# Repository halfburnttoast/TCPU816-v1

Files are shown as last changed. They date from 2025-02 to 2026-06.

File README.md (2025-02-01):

# TCPU816 - Version 1

This is the official repository for my TCPU816, 8-bit, homebrew computer. The computer is a completely custom architecture using 74-series logic gates and EEPROMs. 

The overall goals of this project were to:
* Minimize the chip count.
* Use the fewest EEPROM's possible.
* Avoid using PLAs, CPLDs, and microcontrollers. 
* Maximize stability and operating speed.
* Leave the most amount of RAM possible to the user.
* Make the project fully open-source for others to tinker with and learn from.

## To Do (in no particular order)

* Create standalone emulator for this computer (in C/Rust/Python/etc...)
* Improve the assembler to allow for a more 6502-style syntax (rather than relying on opcode names to define the variants).
* Research adding interrupts to the computer and what kinds of changes would need to happen.
* See the TODO.docx for bugs and improvements. This can be found in 'TCPU816 Computer v1/Hardware/TODO.docx'.

## Purpose

I've had a strong interest in computer design since I was a teenager and had developed multiple CPU implementations in software. But, I've always had a dream of making my own computer from scratch on real hardware. 

The project has been a great learning experience and challenge. In several ways, it let me break away from traditional CPU architecture and test out experimental designs (specifically, minimizing buffer registers and repurposing the MAR to increase efficiency).

## Features and shortcomings
I've tried to keep this computer streamlined and minimalist, focusing on balancing a low chip count and efficiency. But, focusing on one design philosophy usually excludes the other. So, after careful design, the computer has taken the following form:

* Rich, complex instruction set comparable to the 65C02 (but not binary compatible).
* Heavy optimization of the sequencing logic to allow the microcode to fit onto just two EEPROMs.
* Internal memory and IO separation. The external IO exists on a separate address space from the internal memory. This preserves the usable RAM space while allowing the IO cards to make use of the full 16-bit address bus. This also helps reduce address decoding logic. 
* Minimal ROM space. In order to maximize the available RAM, the ROM is limited t a 2Kb block at the beginning of the memory address space. The intention is that this 2Kb block will contain a small monitor and/or bootloader. The actual program storage will be from an SD card on the external bus. 
* Multi-phase clock generation. The phases allow for proper timing between events on the board to eliminate race conditions. It also allows for faster operating speeds overall because it allows multiple conflicting microinstructions to happen during the same CPU cycle without threatening the stability.

There are some pitfalls with this design, however:

* Due to the minimalist ALU design, logic operations take a lot longer to run.
* The computer does not support interrupts at all. This may be something that can be addressed later on. But, for now, there is no clean solution for adding interrupt support. For now, IO is done through polling.
* The design of the address controller limits the possible operating frequency to the maximum response time of the RAM and ROM. This is okay for me because I don't expect (or need) this computer to run any faster than around 3.3MHz. But, the design decisions for this computer make the architecture difficult to scale upwards.

## Licensing 

Licensing hardware is notoriously difficult. Ideally, I'd like the software to be under the GPLv2 license and the hardware to be under the CERN-OHL-S-2.0 license. 

I wouldn't be able to do all this without the vast open-source resources available for electrical engineering and computer design, a lot of which is open source. So, this is my contribution back to that. Hopefully this computer can serve as a learning tool. But, even if the design just gives you an idea or a different way to look at computer design, that's good enough for me!

I'd appreciate a reference if you build off of this design and encourage you to share your improvements back with the community.

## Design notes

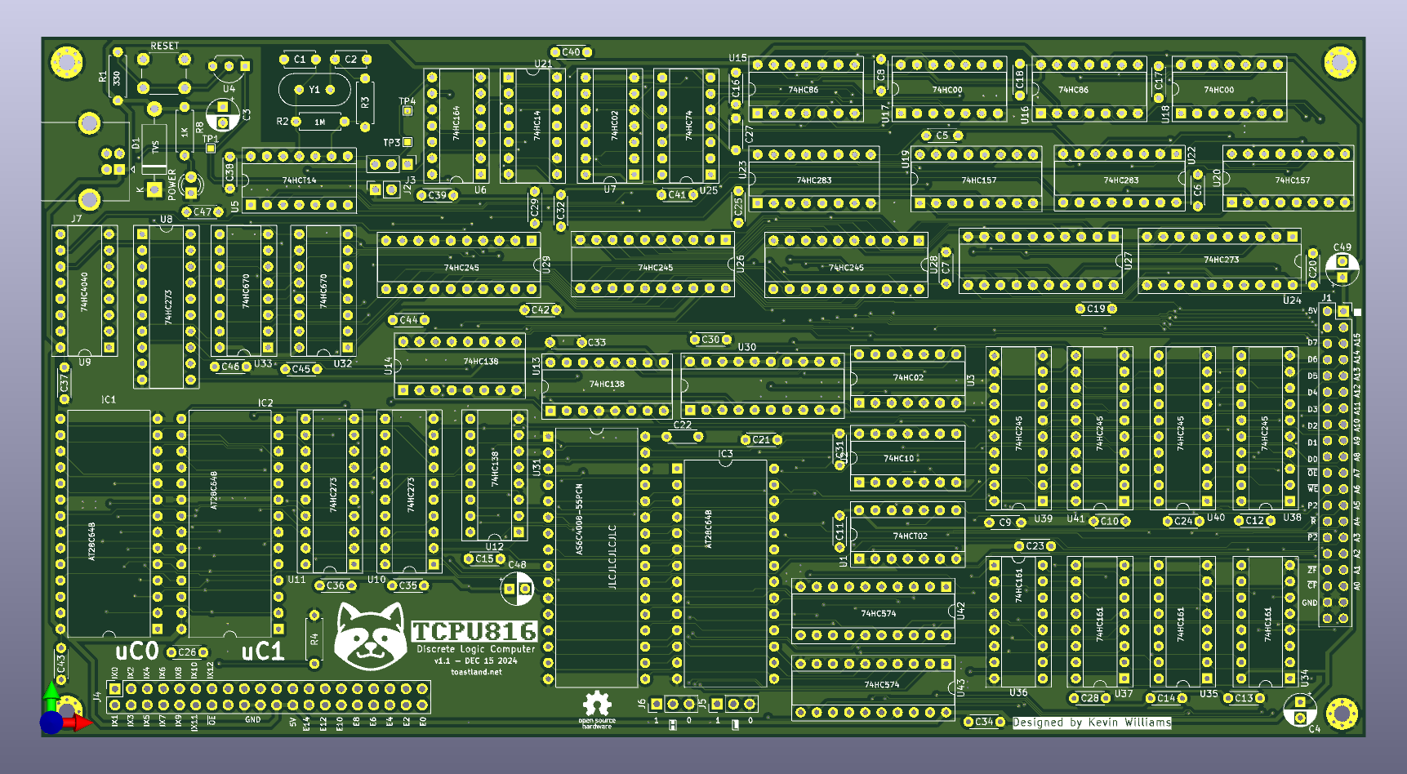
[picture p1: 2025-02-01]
TCPU816 Computer v1/Hardware/8_16_computer_2board.png

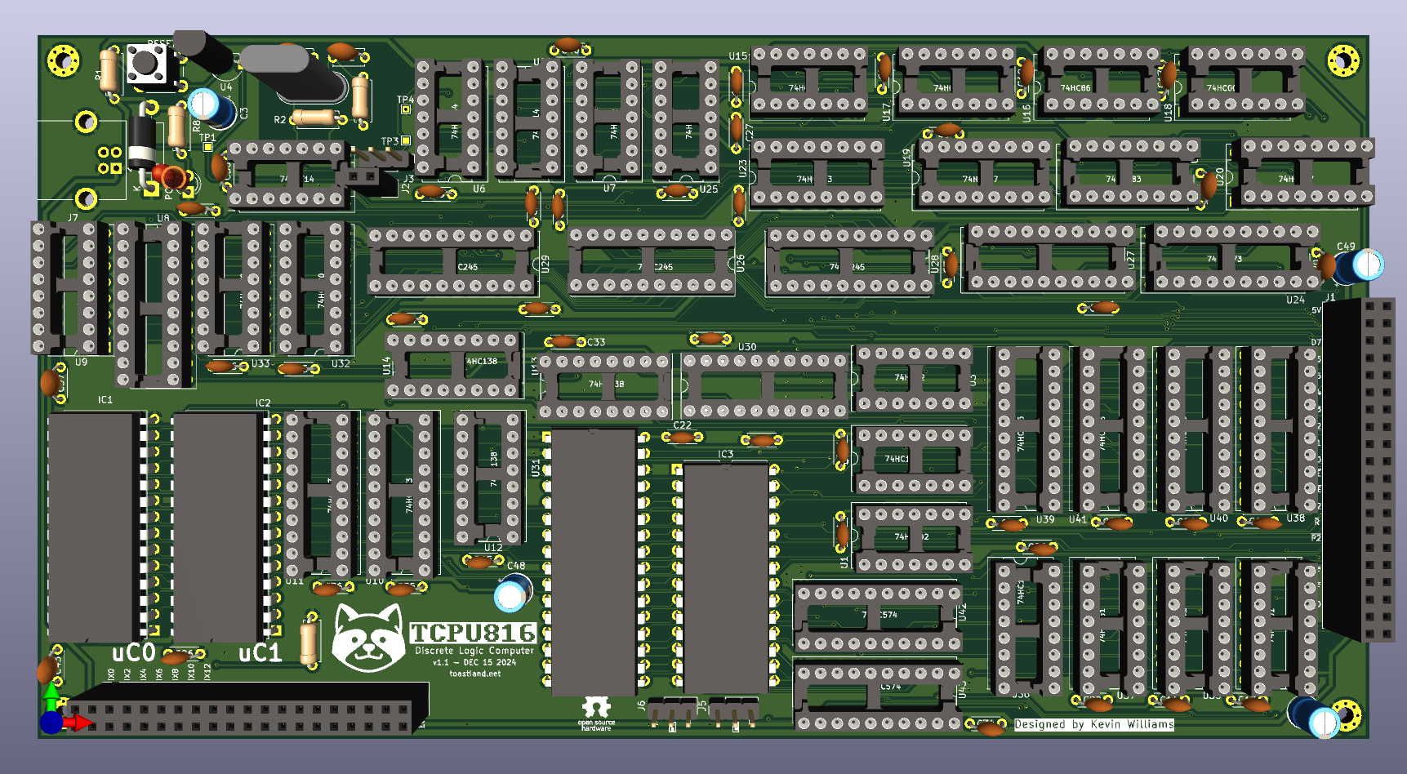
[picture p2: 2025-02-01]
TCPU816 Computer v1/Hardware/8_16_computer_2fc.png

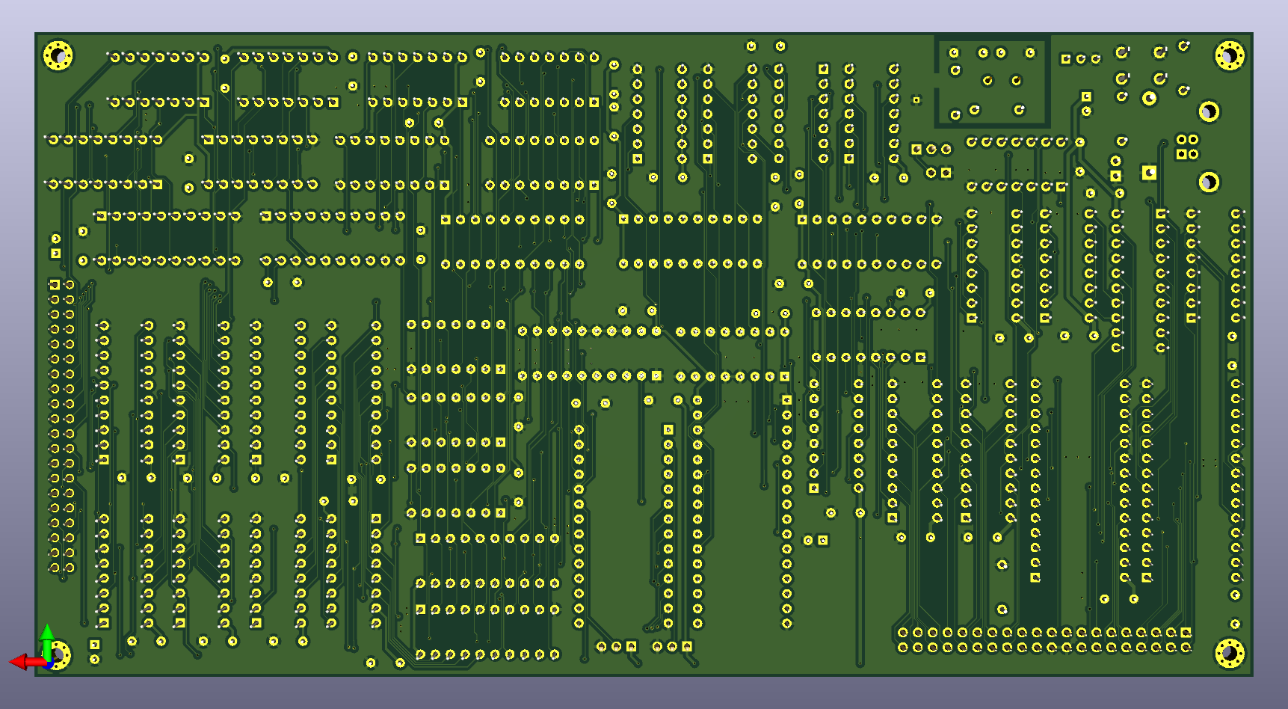
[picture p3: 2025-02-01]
TCPU816 Computer v1/Hardware/8_16_computer_2bc.png

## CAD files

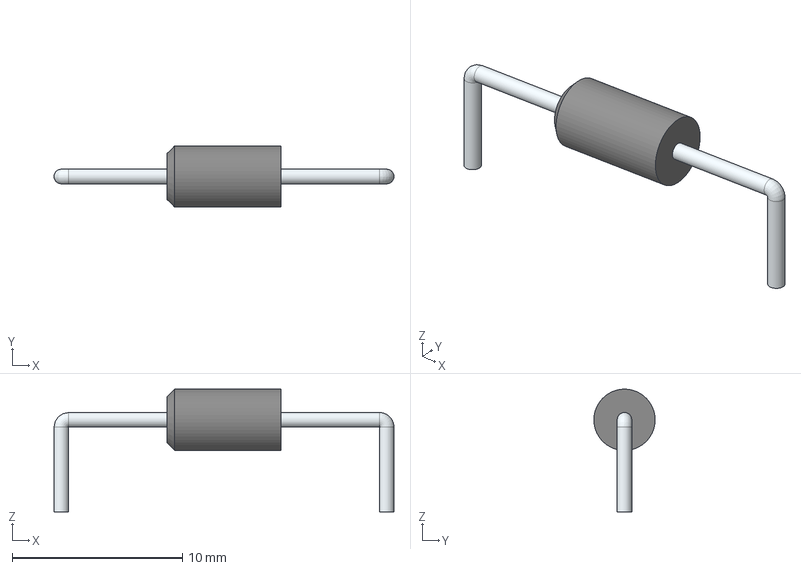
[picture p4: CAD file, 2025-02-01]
TCPU816 Computer v1/Hardware/KiCad/SA5.0A.stp
20.0 x 3.60 x 7.20 mm

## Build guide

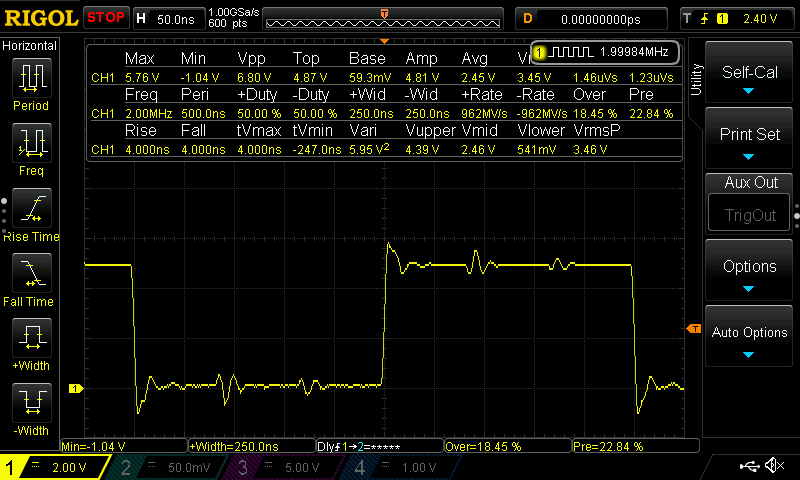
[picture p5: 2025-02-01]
TCPU816 Computer v1/Hardware/measurements/TCPU816-1.0-overshoot-clkp1/DS1Z_QuickPrint1.png

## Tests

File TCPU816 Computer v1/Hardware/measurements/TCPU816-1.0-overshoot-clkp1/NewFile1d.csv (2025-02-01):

X | CH1 | Start | Increment
Sequence | Volt | -3.000000e-07 | 1.000000e-09
0 | 2.80e+00
1 | 2.88e+00
2 | 2.80e+00
3 | 2.80e+00
4 | 2.80e+00
5 | 2.80e+00
6 | 2.80e+00
7 | 2.80e+00
8 | 2.80e+00
9 | 2.80e+00
10 | 2.80e+00
11 | 2.80e+00
12 | 2.80e+00
13 | 2.80e+00
14 | 2.80e+00
15 | 2.80e+00
16 | 2.80e+00
17 | 2.80e+00
18 | 2.80e+00
19 | 2.80e+00
20 | 2.80e+00
21 | 2.80e+00
22 | 2.80e+00
23 | 2.80e+00
24 | 2.80e+00
25 | 2.80e+00
26 | 2.80e+00
27 | 2.80e+00
28 | 2.80e+00
29 | 2.80e+00
30 | 2.80e+00
31 | 2.80e+00
32 | 2.80e+00
33 | 2.80e+00
34 | 2.80e+00
35 | 2.80e+00
36 | 2.80e+00
37 | 2.80e+00
38 | 2.80e+00
39 | 2.80e+00
40 | 2.80e+00
41 | 2.80e+00
42 | 2.80e+00
43 | 2.80e+00
44 | 2.80e+00
45 | 2.80e+00
46 | 2.80e+00
47 | 2.80e+00
48 | 2.32e+00
49 | 1.52e+00
50 | 4.00e-01
51 | -8.80e-01
52 | -2.00e+00
53 | -2.80e+00
54 | -3.12e+00
55 | -3.12e+00
56 | -2.96e+00
57 | -2.80e+00
58 | -2.64e+00
59 | -2.64e+00
60 | -2.64e+00
61 | -2.64e+00
62 | -2.40e+00
63 | -2.24e+00
64 | -2.00e+00
65 | -1.84e+00
66 | -1.68e+00
67 | -1.68e+00
68 | -1.68e+00
69 | -1.76e+00
70 | -1.84e+00
71 | -1.92e+00
72 | -2.00e+00
73 | -2.08e+00
74 | -2.08e+00
75 | -2.16e+00
76 | -2.16e+00
77 | -2.16e+00
78 | -2.08e+00
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

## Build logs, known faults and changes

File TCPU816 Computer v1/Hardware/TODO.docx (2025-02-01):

VERSION 1.1

ERRORS:

1. IR/IRX -> EEPROM address lines are mixed up and not contiguous.
2. U2 has the wrong silk-screen label (should be 74HC132, not 74HC10)
3. CARRY_CLR/CARRY_SET disables CONST_OE_00, causes floating databus.
4. Accidentally changed the 74HC161’s (program counter) parallel input from the MAR output bus to the general address bus. This means MAR_SEL must be asserted when doing any JMP microinstructions. Otherwise the program counter will load its own value, canceling out the JMP instruction.
5. There is a very low chance of the reset operation causing a crash on bootup, at least at lower clock frequencies. Haven’t confirmed it. But, I think this is caused by the RESET line from the supervisory circuit going high at a particular IRX value and clock phase. I’ve only seen this happen at low clock frequencies so far (under 100KHz when using the crystal clock bypass, J2).

IMPROVEMENTS FOR NEXT VERSION:

1. Change USB port direction to point up.
2. Debug header (J4) can be reduced in size or even removed entirely.
3. Take out U5F from the reset line for U9 (74HC4040). Replace with the unused U2D (74HC132). This would allow the 74HC4040 to be reset by both IRX_CLR and the supervisory POR circuit. This should eliminate error 5.

NOTES:

- Internal frequencies are defined by the crystal speed divided by 6, one for each of the six phases. Thus (12MHz/6 = 2MHz).
- Board is fully operational and stable at the on-board 2MHz clock rate (12MHz crystal). Design is fully static to allow for stopping the clock entirely. Under testing, the computer remains running up to around 3.8MHz (~23MHz crystal). But, this may or may not be very stable.
  - I’d need to do more analysis to see what the actual maximum frequency is. But, for now, I’m going to say that the internal clock shouldn’t exceed 3.3MHz (20MHz crystal).
    - This is due to the EEPROM’s 150ns address decoding time. For the three safe phases that the EEPROM address decoding is afforded, each phase delay needs to be 50ns apart. 50ns * 6 = 300ns. 1/300ns = ~3.333MHz.
    - That being said, it’s possible that part of -CLK_P2 could be added to that calculation. For example, during -CLK_P2, the instruction register latches, which is the final change made to the EEPROM addresses during that cycle. For the 74HC273, that event may be around ~45ns, which would leave a fractional value of -CLK_P2’s time that could be added to the above calculation. This could put the true maximum frequency closer to 3.5 or 3.6MHz.
    - But, the effective difference between 3.3MHz and ~3.6MHz isn’t really worth it. The better move would be to use faster EEPROMs.
    - Under testing, the computer loses stability completely at around 4MHz internal clock (24MHz crystal). This makes sense as it would give the EEPROMs (even accounting for the possible “fractional cycle” mentioned above) less than 150ns to decode their address lines.
- Computer draws around 150mA (enabling status LEDs pushes it to 180mA). d
- When programming the microcode EEPROMs, make sure to account for error #1. The EEPROM programmer must take the address line mixup into account. Right now, I’m solving this in software for the EEPROM writer.
- Because of error #3, you can not write a zero value to a register/memory at the same time you use CARRY_CLR/CARRY_SET when nothing is writing to the databus. For example, the microcode instruction:

ALU_EN | CARRY_CLR

gives the impression that it will be latching a zero value to the accumulator. But, in fact, the databus is floating because CONST_OE_00 is excluded from enabling from CARRY_CLR.

- IMPORTANT: If you want to use a 74HC541 in place for U27, U1 MUST be a 74HCT10. The inputs for U1 must be TTL logic compatible.

VERSION 1.0

ERRORS:

1. U6 GND not routed
2. U30A – RAM/ROM selector will not work. Fatal
3. U27A – ZF detector will not work. Fatal
4. uC ICP can be removed. Won’t work without removing IR and IRX.

IMPROVEMENTS FOR NEXT VERSION:

1. Change USB power interface for molex.
2. CV generator 01 value unused.

NOTES:

No further testing can be done because of error 2 and 3. Board is unfixable. Figured out these problems just after I soldered the board together. Oops.

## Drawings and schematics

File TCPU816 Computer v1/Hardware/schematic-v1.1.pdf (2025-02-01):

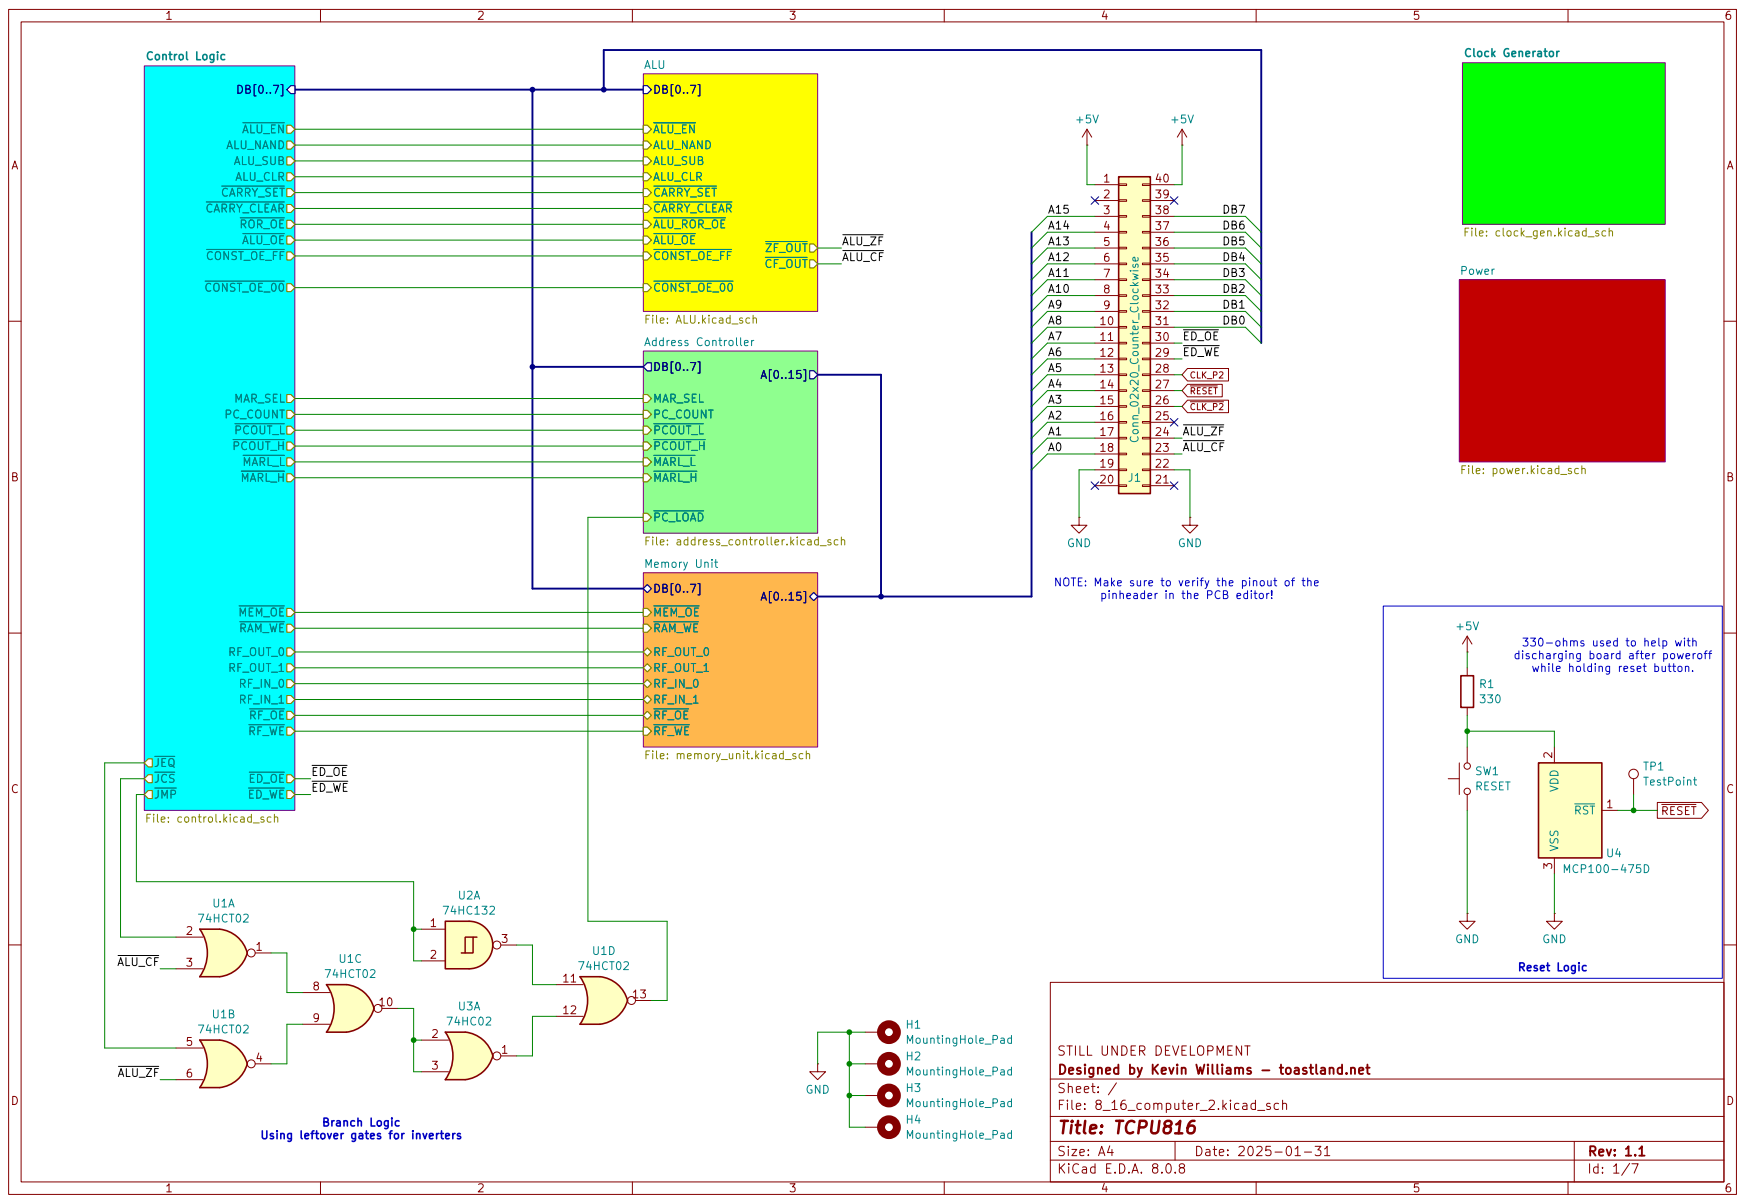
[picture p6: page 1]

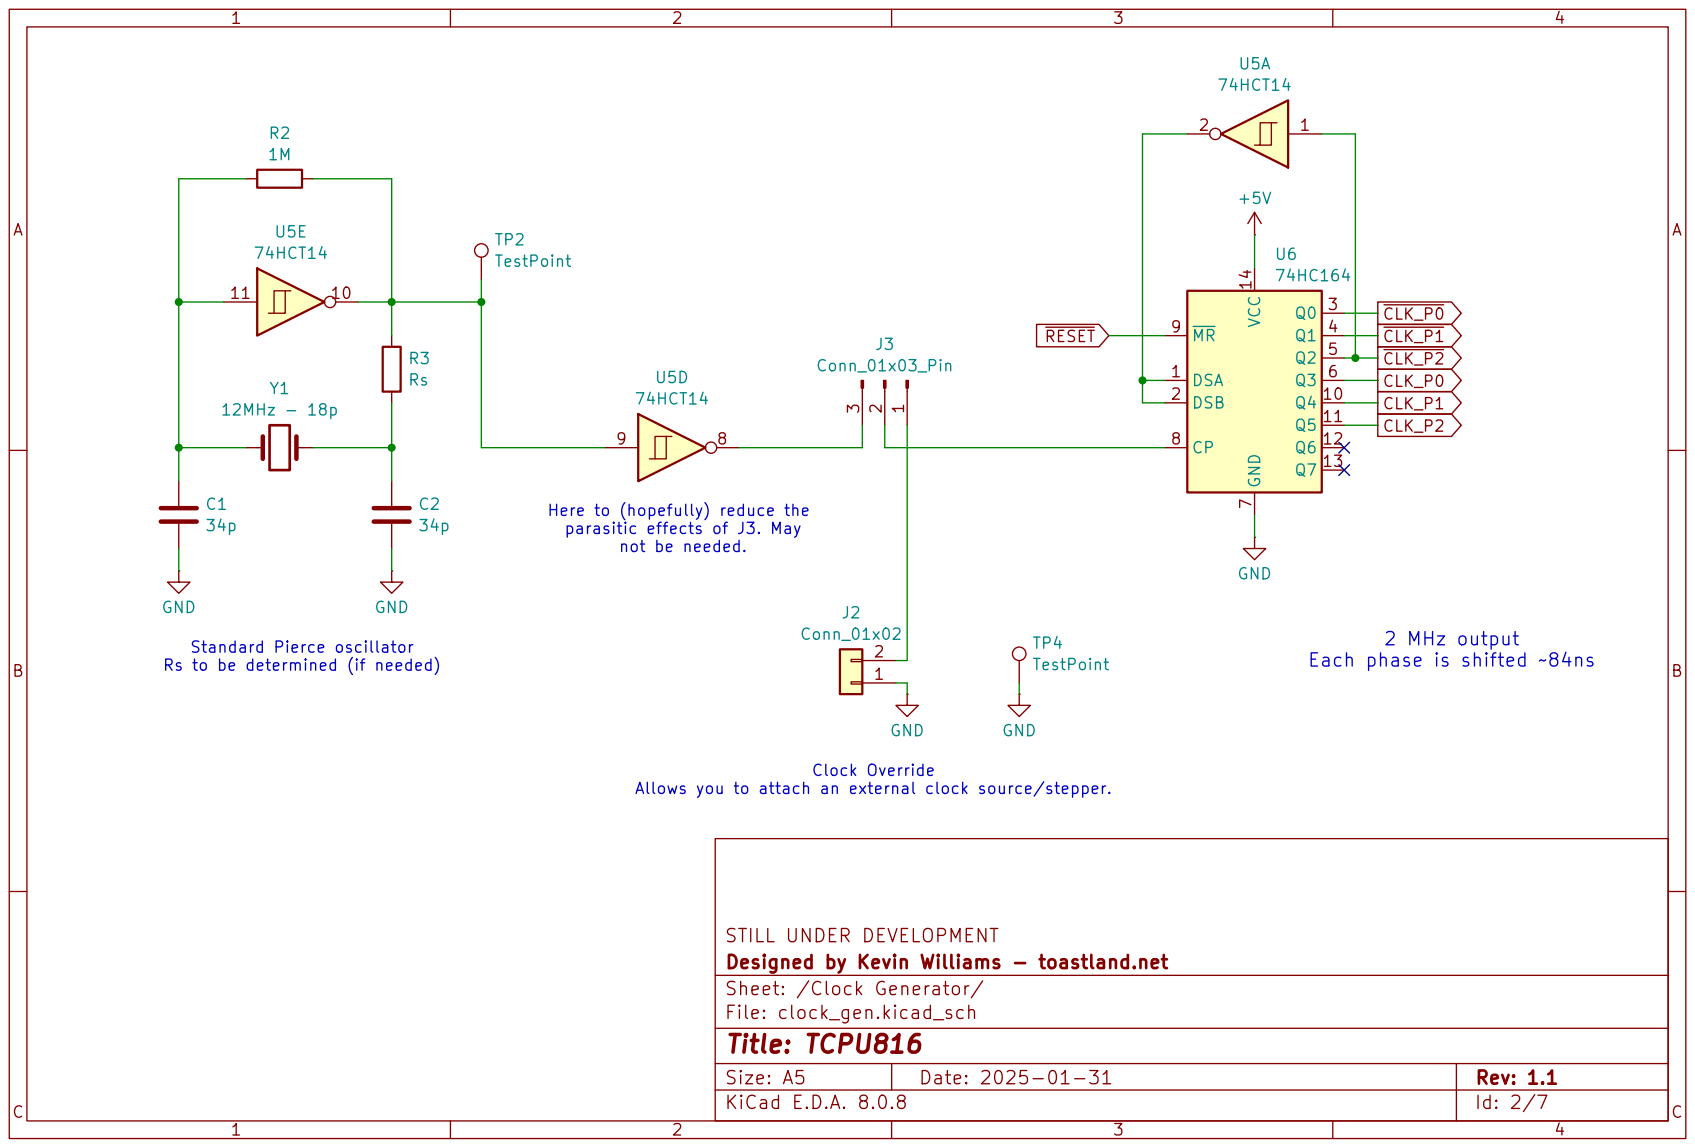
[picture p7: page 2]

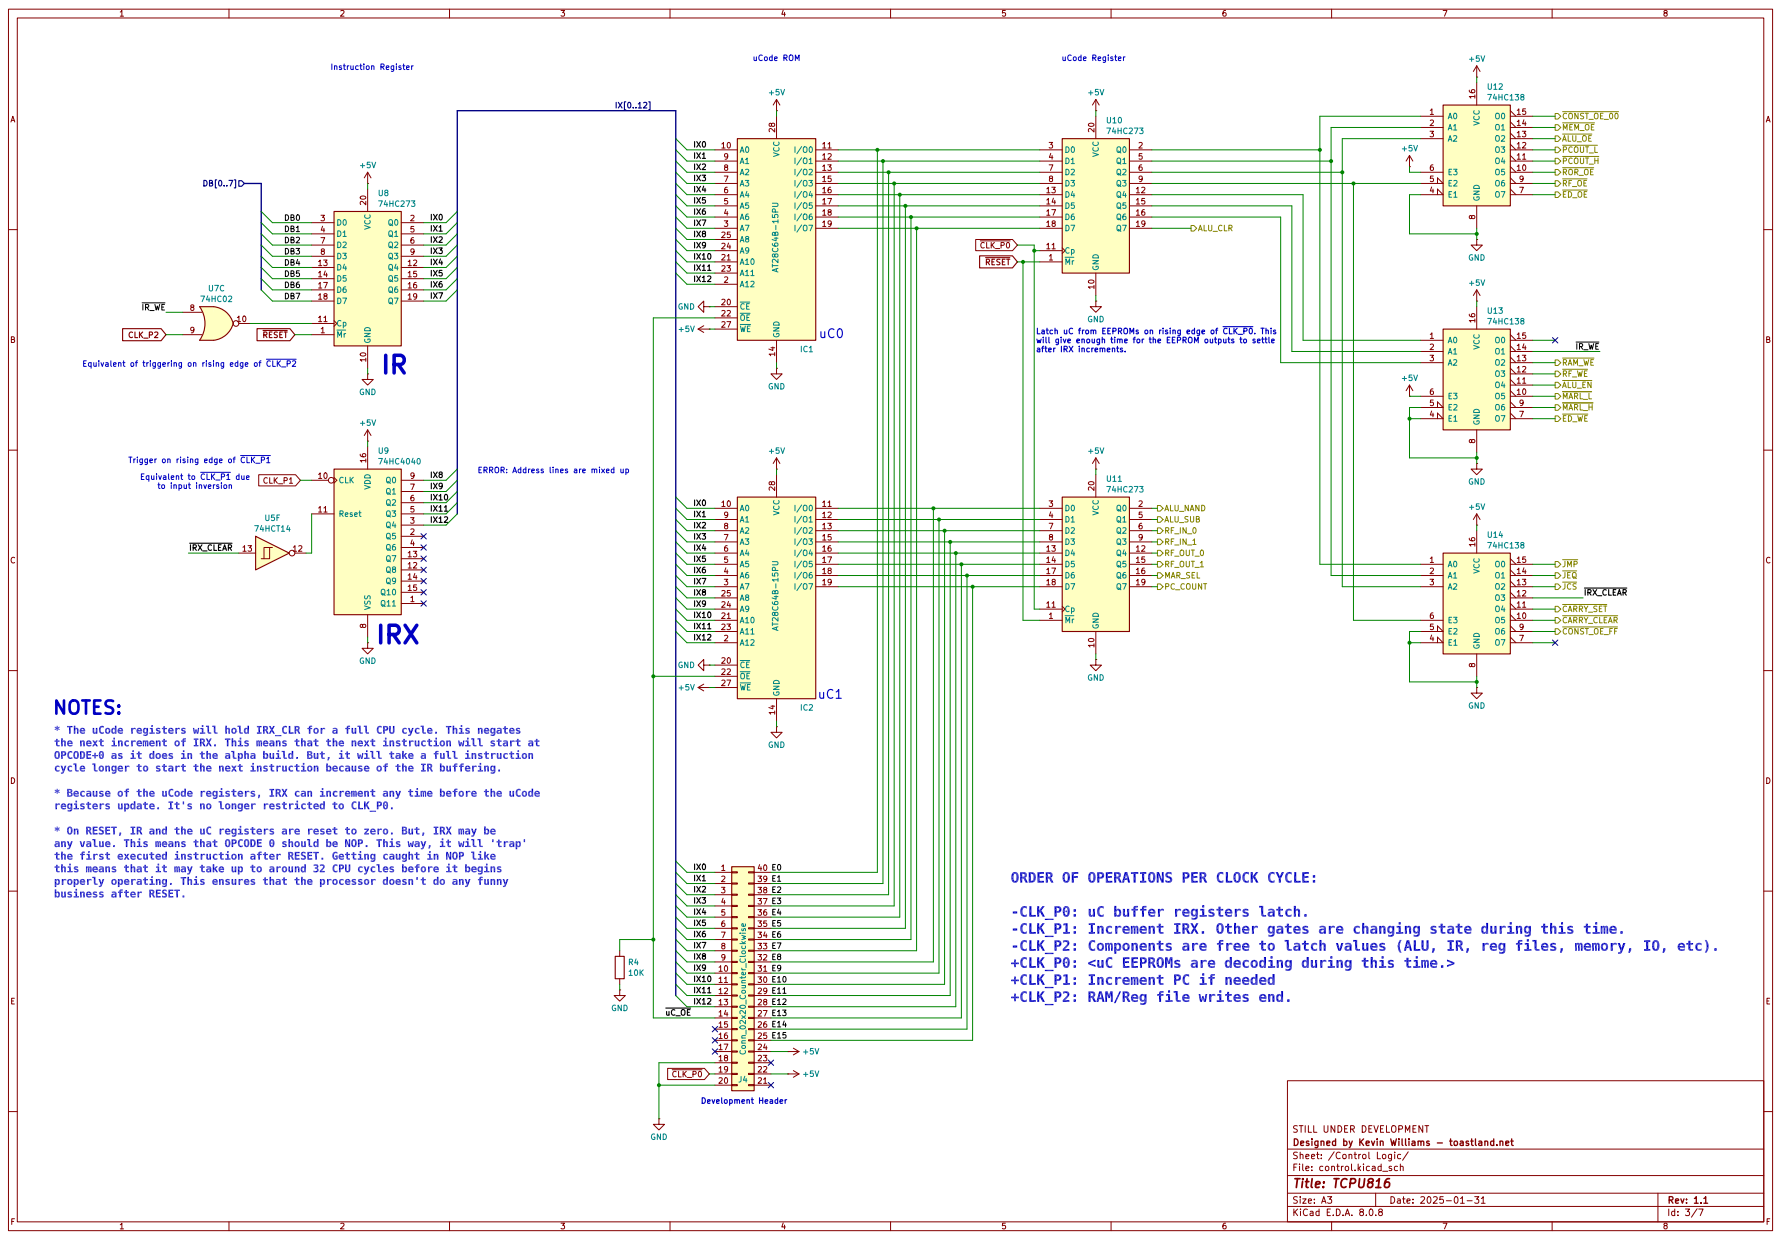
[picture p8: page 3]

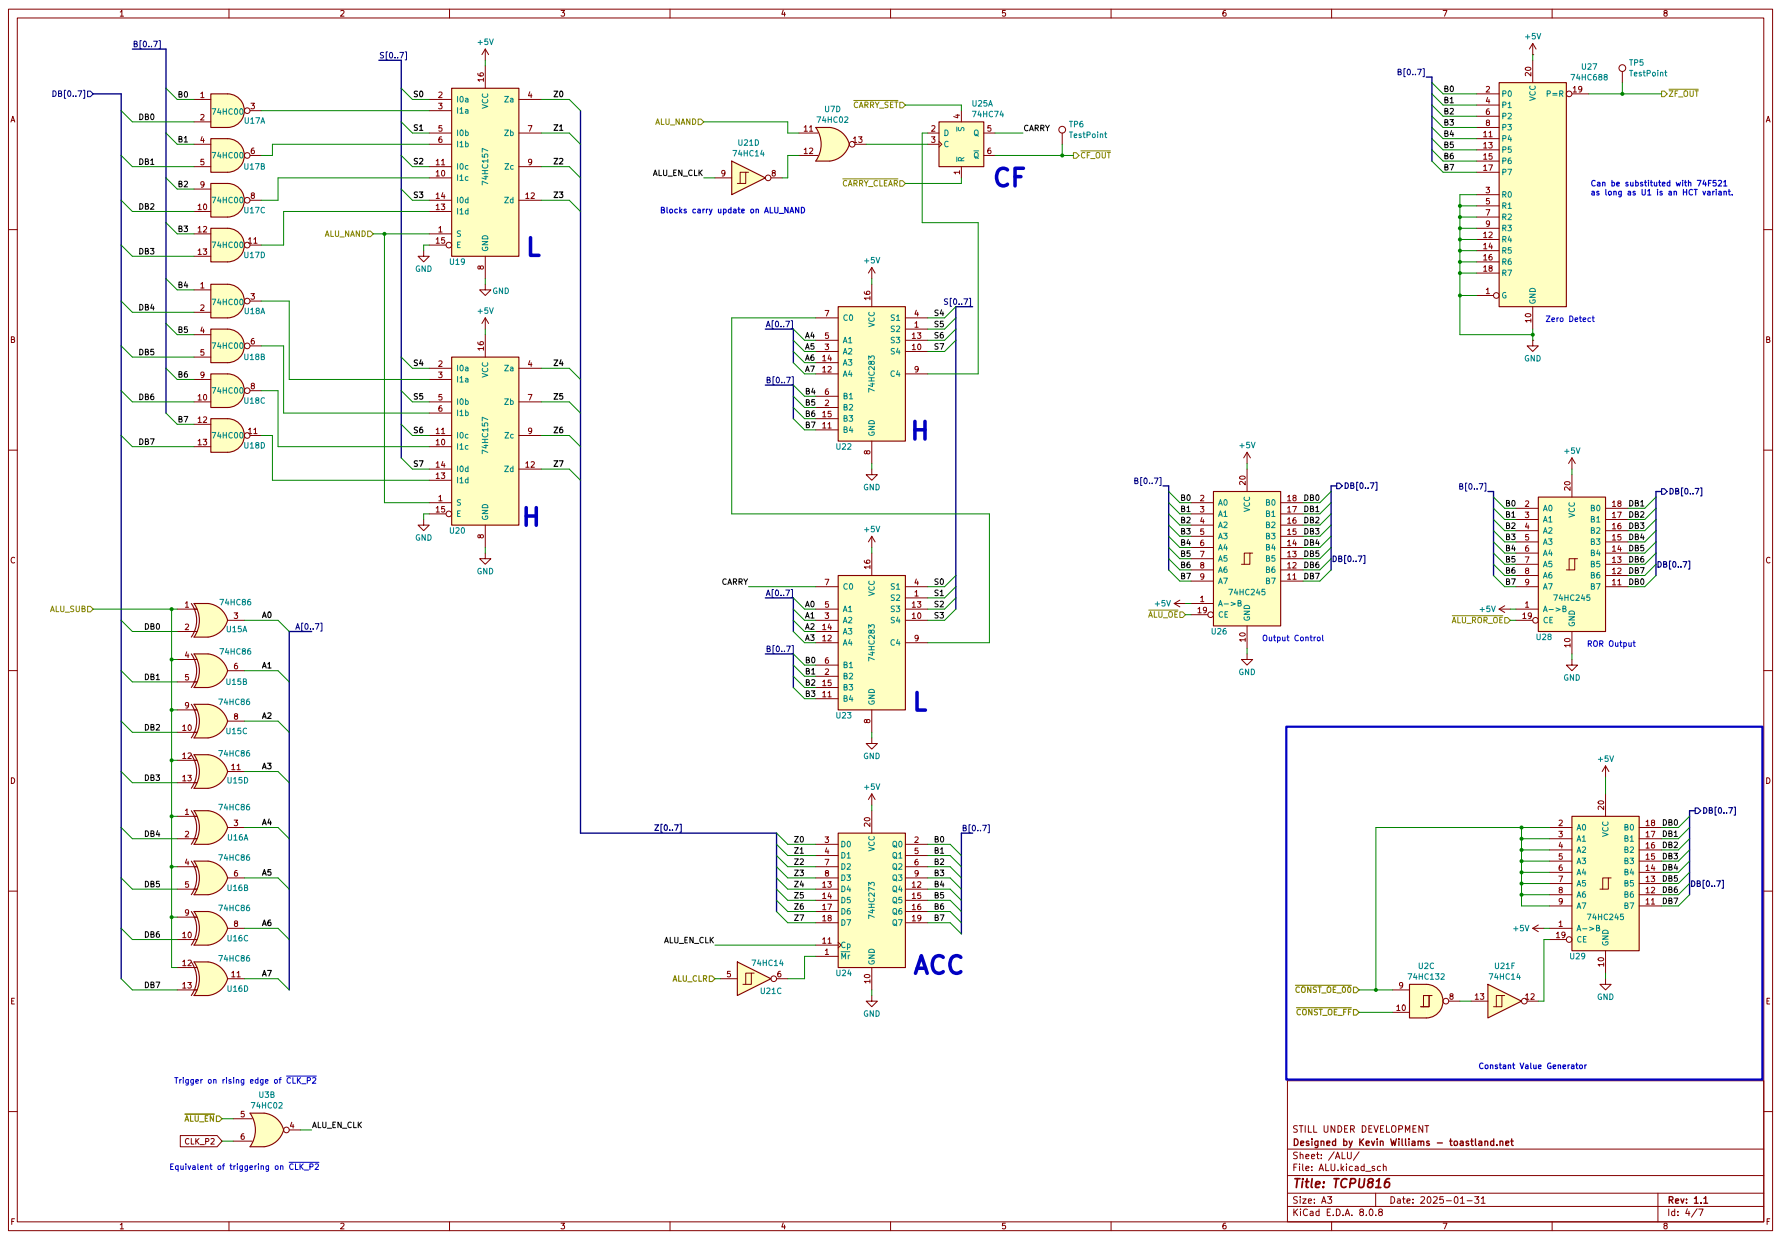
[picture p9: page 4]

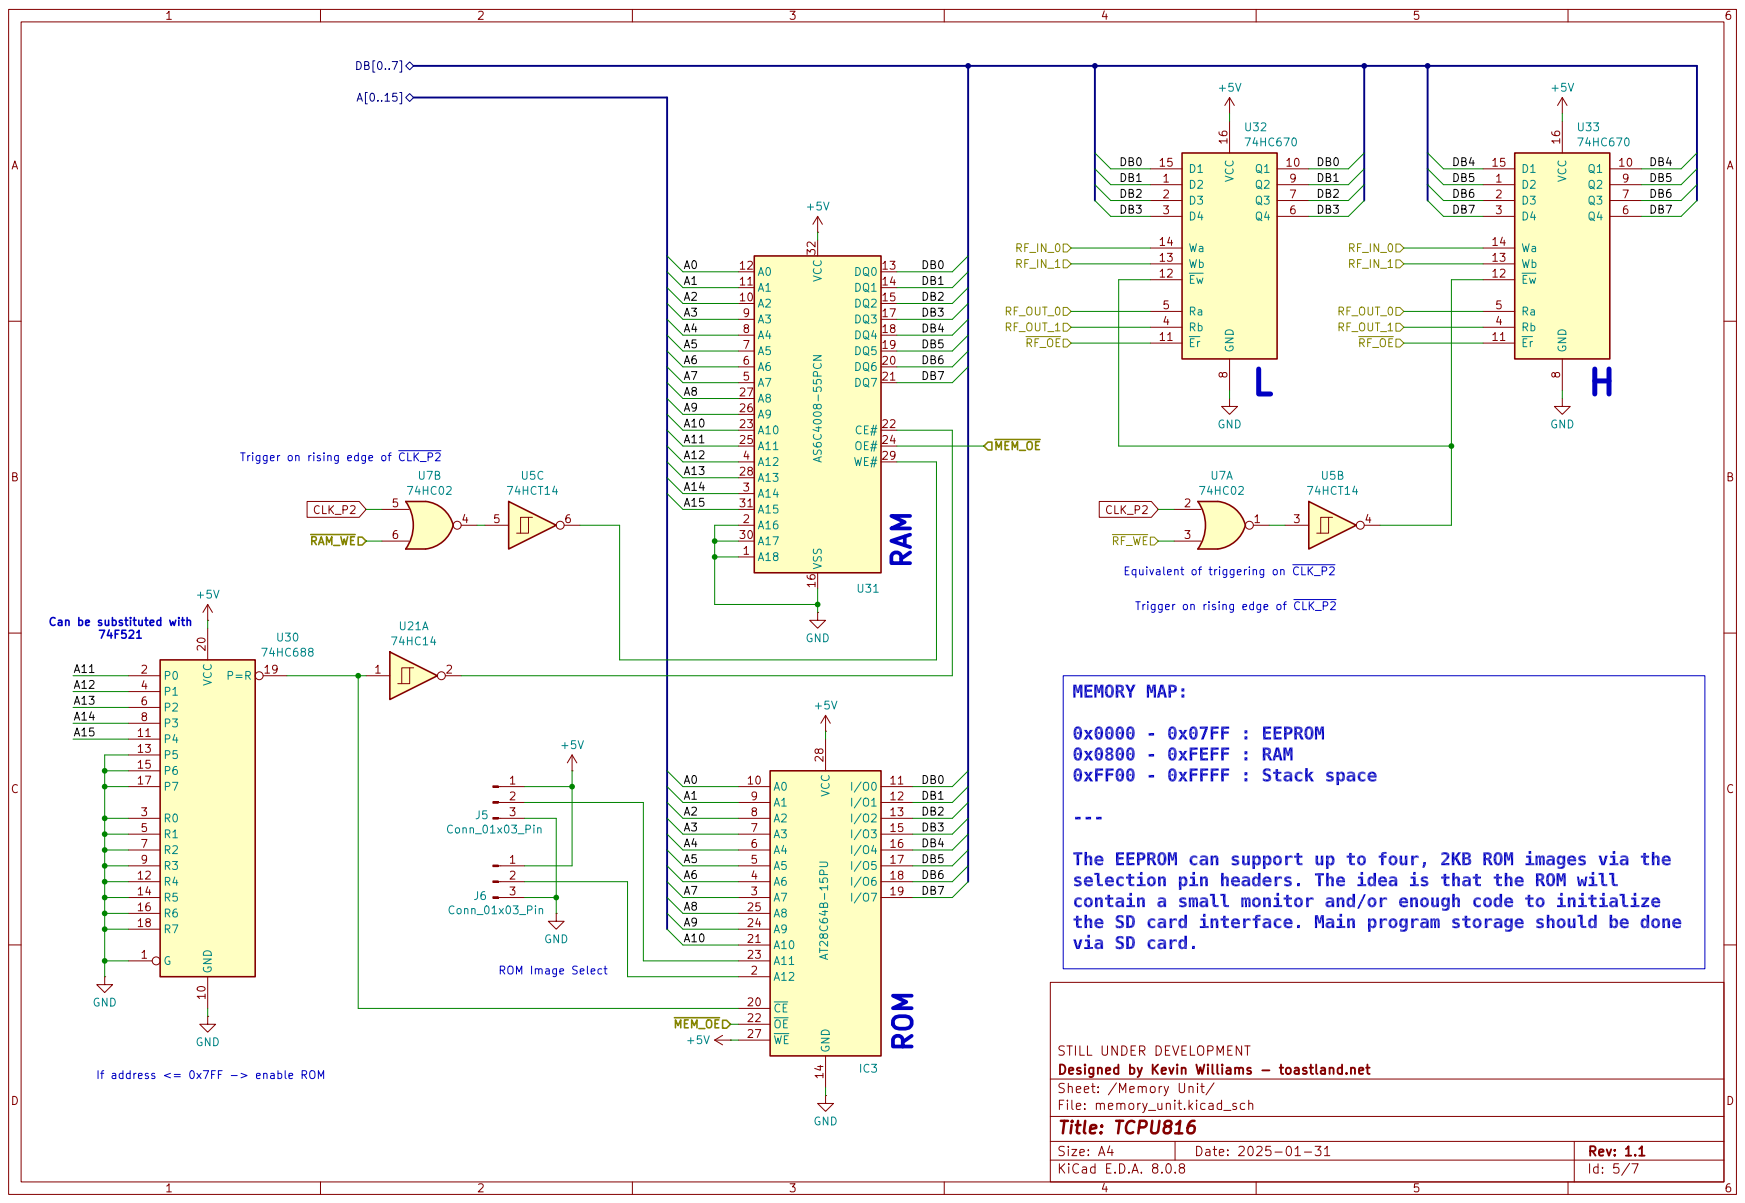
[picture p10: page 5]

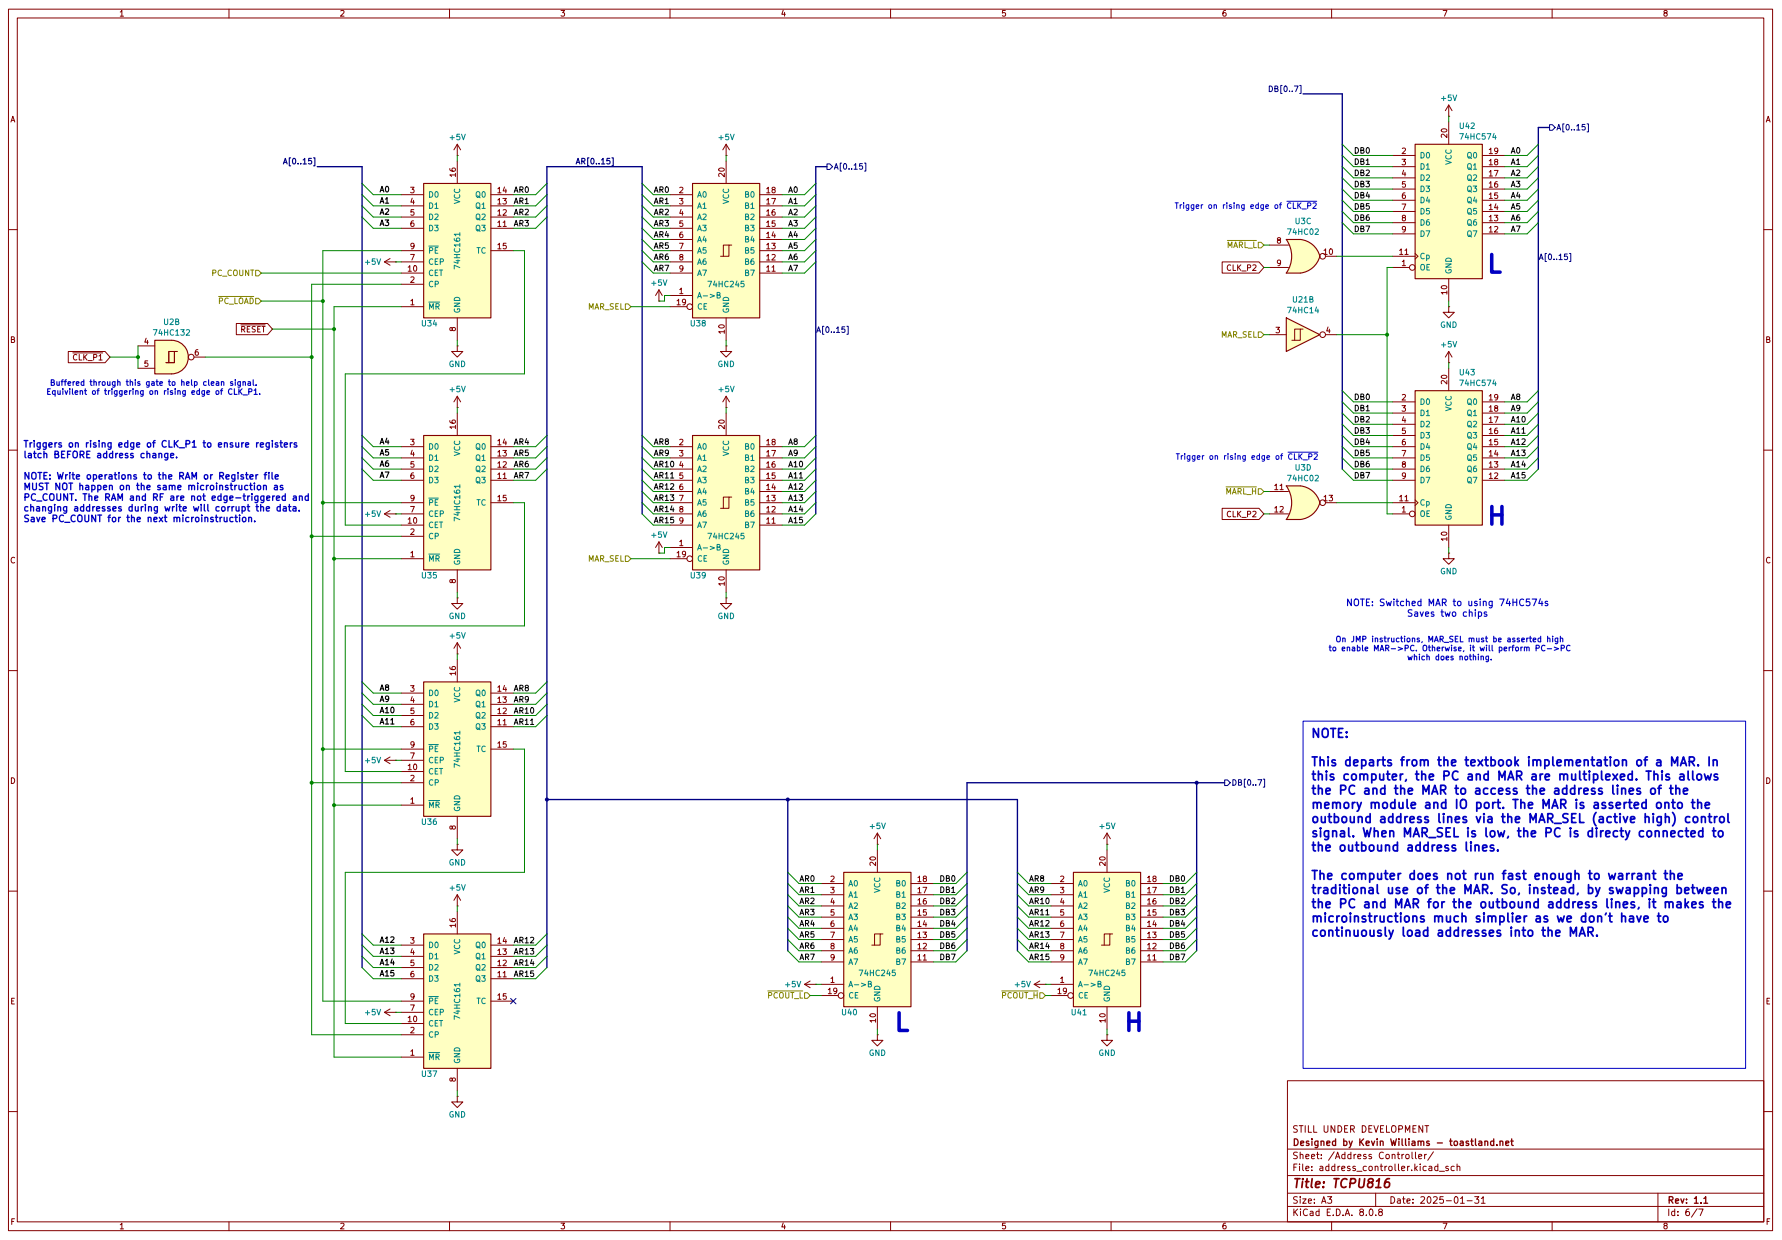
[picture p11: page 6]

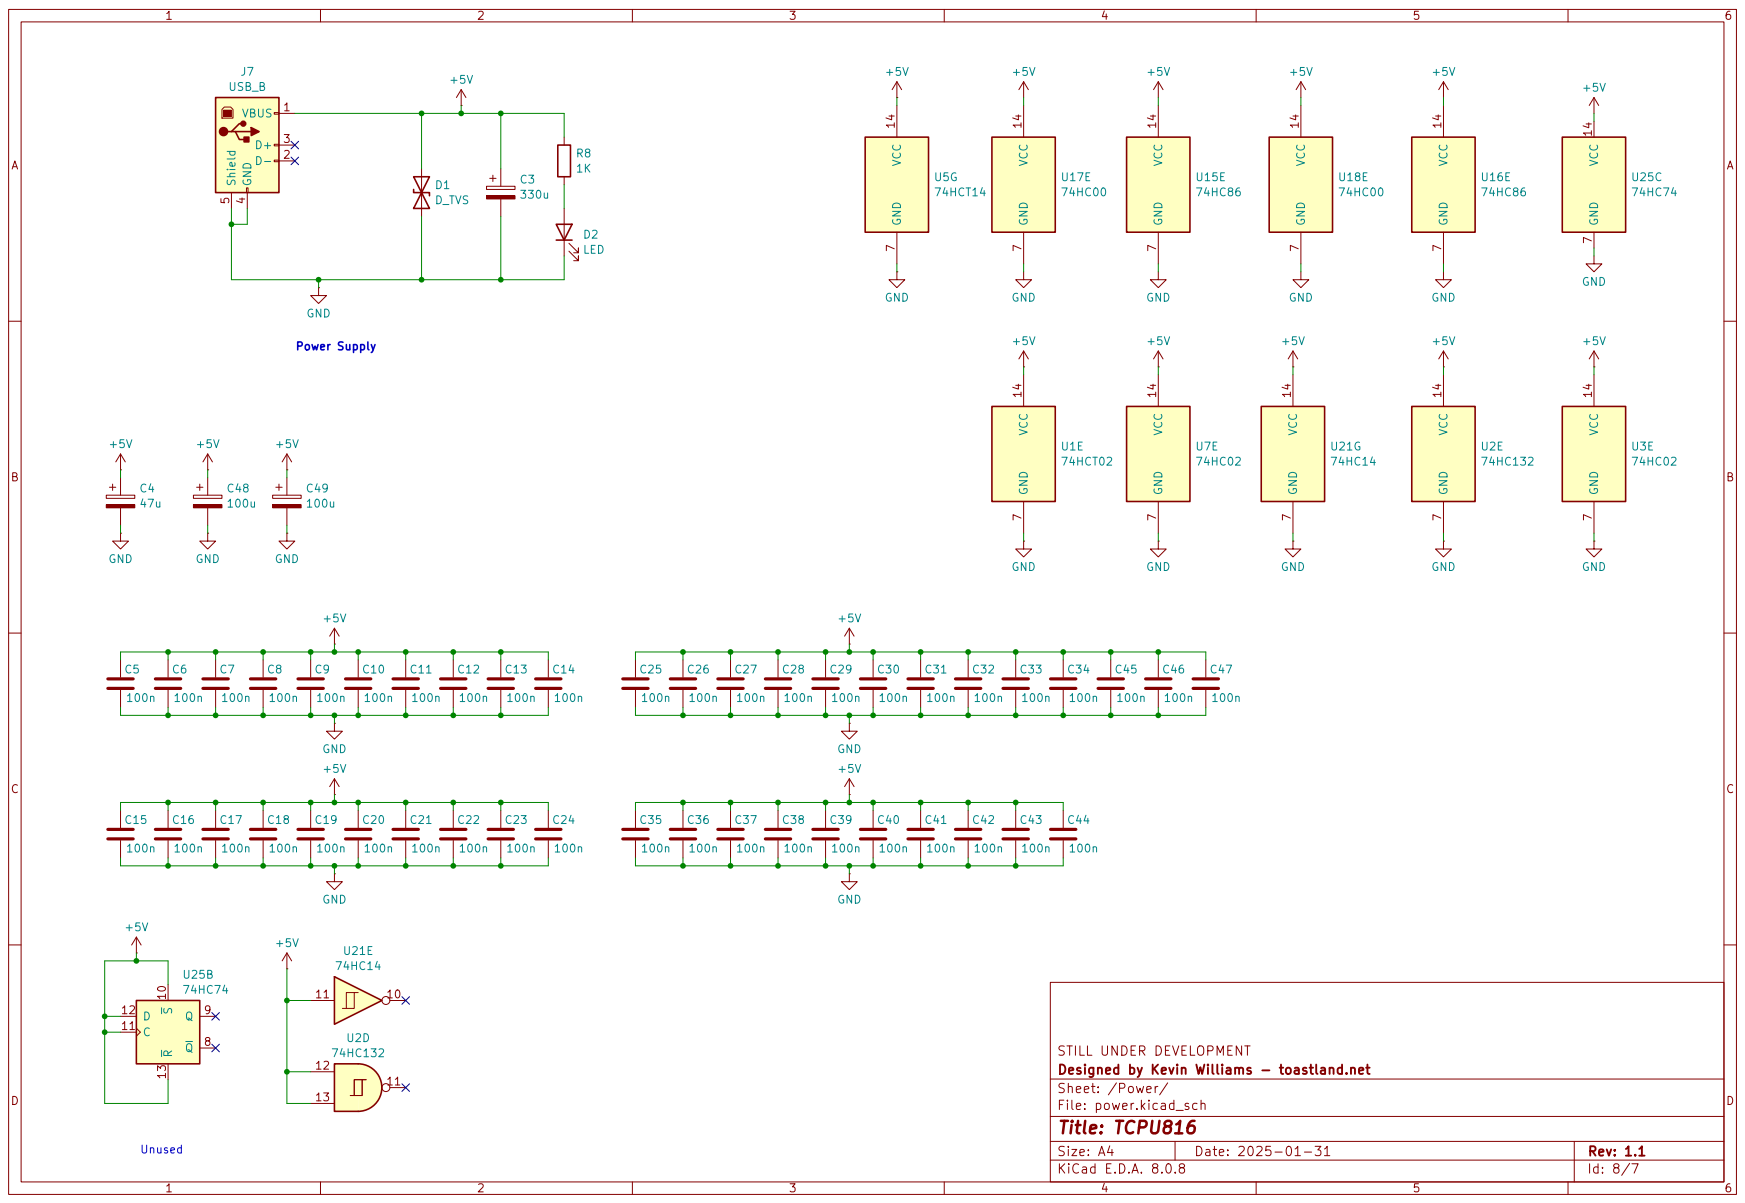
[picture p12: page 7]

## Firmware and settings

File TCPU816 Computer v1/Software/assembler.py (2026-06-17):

#!/usr/bin/env python3

#     The creation of this computer, and all related programs, was only possible
#     due to the incredible amount of open-source, freely available information
#     on electrical/computer/software engineering. So, I want this project in its
#     entirety to be open-source.

#     None of this code was written with AI. <3

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

import argparse
import enum
import inspect
import json
import logging
import re
from dataclasses import dataclass
from pathlib import Path
from typing import LiteralString

__version__ = '0.7.0'


class AssemblyError(Exception):
    def __init__(
            self,
            file_name: str,
            line_num: int,
            message: str,
            context: None | tuple = None
    ) -> None:
        self.file_name = file_name
        self.line_num = line_num
        self.message = message
        self.context = context
        super().__init__(f"{file_name}:{line_num}: {message}")


class AddressMode(enum.Enum):
    NONE = 0
    IMM = 1         # #$12
    IND = 2         # $1234
    DIND = 3        # $(1234)
    INDX = 4        # $1234,X
    INDY = 5        # $1234,Y
    DINDX = 6       # ($1234),X
    DINDY = 7       # ($1234),Y
    SRR = 8         # *($12)
    SRIX = 9        # *($12),X
    SRIY = 10       # *($12),Y


@dataclass
class SourceFile:
    file_name: str
    lines: list


def debug_dump_lines(out_lines: list) -> None:
    for i, v in enumerate(out_lines):
        pad: int = len(str(len(out_lines)))
        logging.debug(f"{str(i).rjust(pad)}: {v}")
    logging.debug("End dump.\n")



def assembly_error(
        file_name: str,
        line_num: int,
        message: str,
        context: None | tuple = None
) -> None:
    calling_function = inspect.stack()[1].function
    line_num = line_num + 1
    logging.fatal(f"[{calling_function}] {file_name}:{line_num}: {message}")
    if context is not None:
        logging.fatal(f"Context: {context}")
    raise AssemblyError(file_name, line_num, message, context)



def decode_argument(arg_str: str) -> list:
    """
    Takes in a 6502 formatted address and determines the
    addressing mode.

    :param arg_str: Raw argument string input (i.e. $(3100) ).
    :return: List containing [address string, addressing mode ENUM value].
    """

    if not hasattr(decode_argument, '_match_patterns'):
        _char_range = r"[0-9A-Z_.]"
        decode_argument._match_patterns = {
            "imm" : re.compile(rf"#([<>]?\$?{_char_range}+)$"),                  # #$12AB or #LABEL   (< or > to indicate high or low byte)
            "ind" : re.compile(rf"(\$?{_char_range}+)$"),                        # $12AB or LABEL
            "dind" : re.compile(rf"\((\$?{_char_range}+)\)$"),                   # ($12AB) or (LABEL)
            "indxy" : re.compile(rf"(\$?{_char_range}+),([XY])$"),               # $12AB,<X or Y> or LABEL,<X or Y>
            "dind_indexed" : re.compile(rf"\((\$?{_char_range}+)\),([XY])$"),    # ($12AB),<X or Y> or (LABEL),<X or Y>
            "srr" : re.compile(rf"\*\((\$?{_char_range}+)\)$"),                  # *($12) or *(LABEL),<X or Y>
            "srrxy" : re.compile(rf"\*\((\$?{_char_range}+)\),([XY])$"),         # *($12),<X or Y> or *(LABEL),<X or Y>
        }
        logging.debug("decode_argument regex patterns compiled.")
    patterns = getattr(decode_argument, '_match_patterns')
    imm_pattern = patterns['imm']
    ind_pattern = patterns['ind']
    dind_pattern = patterns['dind']
    indxy_pattern = patterns['indxy']
    dind_indexed_pattern = patterns['dind_indexed']
    srr_pattern = patterns['srr']
    srrxy_pattern = patterns['srrxy']

    arg_str = arg_str.replace(" ", "").upper()
    if match := re.match(dind_indexed_pattern, arg_str):
        return [match.group(1), AddressMode.DINDX if match.group(2) == "X" else AddressMode.DINDY]
    elif match := re.match(indxy_pattern, arg_str):
        return [match.group(1), AddressMode.INDX if match.group(2) == "X" else AddressMode.INDY]
    elif match := re.match(srr_pattern, arg_str):
        return [match.group(1), AddressMode.SRR]
    elif match := re.match(srrxy_pattern, arg_str):
        return [match.group(1), AddressMode.SRIX if match.group(2) == "X" else AddressMode.SRIY]
    elif match := re.match(dind_pattern, arg_str):
        return [match.group(1), AddressMode.DIND]
    elif match := re.search(imm_pattern, arg_str):
        return [match.group(1), AddressMode.IMM]
    elif match := re.match(ind_pattern, arg_str):
        return [match.group(1), AddressMode.IND]
    else:
        raise ValueError(f"Unknown/malformed argument '{arg_str}'")



def debug_test_arg_parse():
    logging.debug("ARGUMENT DECODE TEST:")
    l = [
        "#<LABEL",
        "#>LABEL",
        "#$1234",
        "#LABEL",
        "$12AB",
        "LABEL",
        "($12AB)",
        "(LABEL)",
        "$12AB,X",
        "$12AB,Y",
        "LABEL,X",
        "LABEL,Y",
        "(LABEL),X",
        "(LABEL),Y",
        "($12AB),X",
        "($12AB),Y",
        "*($12)",
        "*(LABEL)",
        "*($12),X",
        "*($12),Y",
    ]
    for i in l:
        logging.debug(f"{i}: {decode_argument(i)}")


def assemble(lines: list, microcode_table: dict) -> list:
    """
    Assembles the input list into machine code. Automatically handles
    labels and arrays

    :param microcode_table: 
    :param lines: list of line number and line strings.
    :return: asm_out: list of integers (machine code).
    """

    asm_out = []
    label_dict: dict = dict()
    ram_index: int = 0
    insertion_index: int = 0
    index_set: bool = False
    if not hasattr(assemble, '_match_patterns'):
        assemble._match_patterns = {
            "byte_int" : re.compile(r"\$([0-9A-Fa-f]{1,2}$)"),
            "word_int" : re.compile(r"\$([0-9A-Fa-f]{3,4}$)"),
            "label" : re.compile(r"([A-Za-z_.].*)\:$"),
            "substring" : re.compile(r'("([^"]*)"|[^",]+)')
        }
    patterns: dict = getattr(assemble, '_match_patterns')
    byte_int_pattern: re.Pattern = patterns['byte_int']
    word_int_pattern: re.Pattern = patterns['word_int']
    label_pattern: re.Pattern = patterns['label']
    substring_pattern: re.Pattern = patterns['substring']

    # Pass 1: primary assembly
    for file_name, line_num, line_tokens in lines:
        inst = line_tokens[0].upper()

        # process program offset
        if inst == '@':
            if index_set:
                assembly_error(file_name, line_num, "Program memory index already set!")
            else:
                index_set = True
            try:
                ram_index = int(line_tokens[1], 16)
                insertion_index = int(line_tokens[1], 16)
            except IndexError as e:
                assembly_error(file_name, line_num, f"Expected address value after offset declaration. {e}")
            except ValueError as e:
                assembly_error(file_name, line_num, f"Invalid address value. {e}")
            logging.debug(f"RAM index set: {ram_index}")
            continue

        # process label
        if inst[-1] == ':':
            try:
                label_temp: str = re.match(label_pattern, inst).group(1)
            except AttributeError:
                assembly_error(file_name, line_num, f"Invalid label name '{inst}'")
            if label_temp in label_dict.keys():
                assembly_error(file_name, line_num, "Error: label '" + label_temp + "' has multiple definitions")
            label_dict[label_temp] = '{:04X}'.format(int(ram_index.to_bytes(2, 'little').hex(), 16))
            logging.debug(f"Label added: {[label_temp, label_dict[label_temp]]}")
            continue

        # process hex array
        if inst == ".HEX":
            line_tokens.pop(0)
            if not len(line_tokens):
                logging.warning(f"{file_name}:{line_num}: Expected hex values after .hex keyword.")
            try:
                for i in line_tokens[0].split(','):
                    asm_out.append(int(i.strip('$'), 16))
                    ram_index = ram_index + 1
            except ValueError as e:
                assembly_error(file_name, line_num, f"Error parsing hex values. {e}")
            continue

        # process ascii array
        if inst == ".ASCII":
            line_tokens.pop(0)
            for c in line_tokens[0]:
                asm_out.append('{:02X}'.format(ord(c)))
                ram_index = ram_index + 1
            continue

        # process mixed data, comma separated
        if inst == ".BYTE":
            line_tokens.pop(0)
            items = re.findall(substring_pattern, line_tokens[0])
            items = [item[0].strip() for item in items]
            items = [item for item in items if len(item) > 0]
            for t in items:
                if '"' in t:
                    for c in t.replace('"', ''):
                        asm_out.append('{:02X}'.format(ord(c)))
                        ram_index = ram_index + 1
                elif '$' in t:
                    try:
                        num = int(t.strip('$'), 16)
                    except ValueError as e:
                        assembly_error(file_name, line_num, f"Error parsing DATA values. {e}")
                    if num > 0xFF:
                        assembly_error(file_name, line_num, f"DATA value too large. {num}")
                    asm_out.append('{:02X}'.format(num))
                    ram_index = ram_index + 1
                else:
                    try:
                        num = int(t, 10)
                    except ValueError as e:
                        assembly_error(file_name, line_num, f"Error parsing DATA values. {e}")
                    if num > 0xFF:
                        assembly_error(file_name, line_num, f"DATA value too large. {num}")
                    asm_out.append('{:02X}'.format(num))
                    ram_index = ram_index + 1
            continue


        # otherwise process opcode and argument
        opcode_name: str = inst
        addr_mode: str = AddressMode.NONE.name
        argument: None | str | LiteralString = None
        if opcode_name not in microcode_table.keys():
            assembly_error(file_name, line_num, f"Invalid opcode name '{opcode_name}'")

        # detect argument type and value (if applicable)
        if len(line_tokens) > 1:
            try:
                argument, addr_mode = decode_argument(line_tokens[1])
            except ValueError as e:
                assembly_error(file_name, line_num, f"Error parsing arguments. {e}")
            addr_mode = addr_mode.name
        try:
            opcode_dict = microcode_table[opcode_name][addr_mode]
        except KeyError as e:
            assembly_error(file_name, line_num, f"Invalid address mode {e} for opcode '{opcode_name}'")
        except TypeError:
            assembly_error(file_name, line_num, f"No matching addressing mode for opcode '{opcode_name}'")

        # append opcode to output along with arguments. If the argument is a label we need
        # to append the label because we don't know what address the label resolves to yet.
        asm_out.append(opcode_dict['code'])
        ram_index = ram_index + 1
        expected_args = opcode_dict['args']
        if expected_args > 0:
            if argument is None:
                assembly_error(file_name, line_num, f"No argument given for opcode '{opcode_name}' mode '{addr_mode}'.")

            # if this is supposed to resolve to a number (contains '$' before hex digits)
            if '$' in argument:
                word_arg: re.Pattern = re.match(word_int_pattern, argument)
                byte_arg: re.Pattern = re.match(byte_int_pattern, argument)
                if expected_args == 1:
                    if byte_arg:
                        asm_out.append(int(argument.replace('$', ''), 16))
                    elif word_arg:

                        # Attempt to extract the least significant byte from the value if it's < 0x100.
                        # This allows for things like '.alias TEST $11 ; lda #TEST' to work because
                        # process_variables will save the convert the aliased addresses to little-endian
                        # and pad out the most significant byte with zeros.
                        # But, this feels really hacky. Probably should think of something better...
                        val = argument.replace('$', '')
                        val = val[2:] + val[0:2]
                        val = int(val, 16)
                        if val < 0x100:
                            asm_out.append(val)
                        else:
                            assembly_error(file_name, line_num, f"Argument too large for opcode '{opcode_name}' mode '{addr_mode}' : {hex(val)}")
                    else:
                        assembly_error(file_name, line_num, "No matching argument for opcode '{opcode_name}' mode '{addr_mode}. {argument}'")
                elif expected_args == 2:
                    if word_arg:
                        arg = argument.replace('$', '')
                        arg_high = arg[2:4]
                        arg_low = arg[0:2]
                        asm_out.append(int(arg_low, 16))
                        asm_out.append(int(arg_high, 16))

                    # if argument isn't filled completely, convert it to a 16-bit address
                    elif byte_arg:
                        arg_low = argument.replace('$', '')
                        arg_high = 0
                        asm_out.append(int(arg_low, 16))
                        asm_out.append(arg_high)
                    else:
                        assembly_error(file_name, line_num,f"Mismatched argument for opcode {opcode_name} mode '{addr_mode}': {argument}")

            # if there's no $ character, it must be a label
            else:
                if expected_args == 1:
                    asm_out.append(argument)
                elif expected_args == 2:
                    asm_out.append('<' + argument)
                    asm_out.append('>' + argument)
            ram_index = ram_index + expected_args
        else:
            continue
        pass        # put breakpoint here for inter-instruction debugging
    logging.debug("Pass 1 complete.")

    # Pass #2: Replace labels in asm_out with addresses from label_dict
    for i, line in enumerate(asm_out):
        if type(line) is str:
            if line[0] == '>':
                line = line[1:]
                if line[0] == '$':
                    asm_out[i] = line[3:5]
                else:
                    asm_out[i] = label_dict[line][2:4]
            elif line[0] == '<':
                line = line[1:]
                if line[0] == '$':
                    asm_out[i] = line[1:3]
                else:
                    asm_out[i] = label_dict[line][0:2]
    logging.debug("Pass 2 complete.")

    # Pass 3: replace all hex-coded strings with integers
    for i, v in enumerate(asm_out):
        if type(v) == str:
            asm_out[i] = int(v, 16)
    logging.debug("Pass 3 complete.")
    logging.info(f"Program assembled for starting address {'0x{:04X}'.format(insertion_index)}")
    return asm_out




def tokenize_lines(lines: list) -> list:
    """
    Split the string portion of lines into a list of tokens.
    Maintains line numbers.

    NOTE: All lines with the .ascii keyword are added as-is, otherwise
    it will strip the spaces out of strings. .byte supports mixed data
    types including strings. So, it will also not remove spaces or do
    any further formatting.

    Output format now looks like:

    [
        [line number, [token1, token2, ...]],
        ...
    ]

    :param lines: List of line numbers and line strings.
    :return: List of line numbers and line tokens
    """

    if not hasattr(tokenize_lines, "_match_patterns"):
        tokenize_lines._match_patterns = {
            'ascii': re.compile(r"^.ascii\s+\"([^\"]+)\""),
            'byte': re.compile(r"^.byte\s+(.+)")
        }
    patterns: dict = getattr(tokenize_lines, "_match_patterns")
    ascii_pattern: re.Pattern = patterns['ascii']
    byte_pattern: re.Pattern = patterns['byte']

    out_lines = []
    for file_name, line_num, line_str in lines:
        if line_str.startswith('.ascii'):
            if match := re.match(ascii_pattern, line_str):
                out_lines.append([file_name, line_num, ['.ascii'] + [match.group(1)]])
            else:
                assembly_error(file_name, line_num, "Expected character string after .ascii keyword.")
        elif line_str.startswith('.byte'):
            if match := re.match(byte_pattern, line_str):
                out_lines.append([file_name, line_num, ['.byte'] + [match.group(1)]])
            else:
                assembly_error(file_name, line_num, "Expected data string after .byte keyword.")
        else:
            tokens = [t for t in line_str.split(" ") if t]
            inst = tokens.pop(0)
            args = "".join(tokens)
            out_lines.append([file_name, line_num, [inst] + ([args] if args else [])])
    logging.debug(f"Tokenized lines:")
    debug_dump_lines(out_lines)
    return out_lines



def process_variables(lines: list) -> list:
    """
    Locates and processes all variable macros (.alias). Basically the same as
    #define in C header files. Replaces all instances of the label with the literal
    value defined.

    Args    :   lines:list (list of strings)
    Returns :   lines:list (modified)
    """

    if not hasattr(process_variables, "_match_patterns"):
        process_variables._match_patterns = {
            'alias': re.compile(                #       .alias LABELNAME <$12AB or '<single character'>
                r"^.alias\s+"                   # .alias keyword
                r"([A-Za-z_.]+)\s+"             # group 1 - label name, can include underscores and periods
                r"\'?(\$?[A-Za-z0-9]+)'?"       # group 2 - hex address OR character. Capture $ in group if hex number.
            )
        }
    patterns = getattr(process_variables, "_match_patterns")
    alias_pattern: re.Pattern = patterns['alias']

    var_dict = dict()
    pop_list = list()

    # Start by building dict of variables. Save indicies of alias in pop_list
    for i, line_pack in enumerate(lines):
        file_name, line_num, line_str = line_pack
        if line_str.startswith('.alias'):
            if match := re.match(alias_pattern, line_str):
                label_name = match.group(1)
                argument = str(match.group(2))
                if label_name in var_dict:
                    assembly_error(file_name, line_num, f"Variable '{label_name}' already defined.")
                if '$' in argument:
                    try:
                        _arg = int(argument.strip('$'), 16)
                        _arg = _arg.to_bytes(2, 'little').hex().upper()
                    except ValueError:
                        assembly_error(file_name, line_num, f"Invalid numerical value. '{line_str}'")
                    except OverflowError:
                        assembly_error(file_name, line_num, f"Oversized value for alias. '{line_str}'")
                    var_dict[label_name] = '$' + _arg
                    pop_list.append(i)
                elif '\'' in argument:
                    try:
                        _chr = argument.replace('\'', '')
                        _chr = '{:02X}'.format(ord(_chr))
                    except TypeError:
                        assembly_error(file_name, line_num, f"Invalid character alias definition. '{line_str}'")
                    var_dict[label_name] = '$' + _chr
                    pop_list.append(i)
            else:
                assembly_error(file_name, line_num, f"Expected label and value after .alias keyword.")

    # remove all alias definitions from code base
    for i in pop_list[::-1]:
        lines.pop(i)

    # replace all instances of alias with real value
    for i, line in enumerate(lines):
        file_name, line_num, line_str = line
        for key in var_dict.keys():
            if key in line_str:
                out = re.sub(r"\b" + re.escape(key) + r"\b", var_dict[key], line_str)
                lines[i] = [file_name, line_num, out]
    logging.debug("VAR DICT (addresses are little-endian):")
    logging.debug(var_dict)
    logging.debug("After variable processing:")
    debug_dump_lines(lines)
    return lines
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

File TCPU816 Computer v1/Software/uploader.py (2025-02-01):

#       
#  Written by HalfBurntToast
#
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


#!/usr/bin/python3
import serial
import serial.tools.list_ports
import argparse
import time

g_rate = 19200 
g_ser  = None
g_line_delay = 0.03
g_char_delay = 0.002

def main():

    # parse args
    parser = argparse.ArgumentParser(epilog = '''
        A tool to copy assembled ROM images into the TPC65's RAM at a given location.\n
        Interfaces with the TMON monitor to upload programs.
        ''')
    parser.add_argument("offset", help = "insert code into this hexadecimal address. (ex. 04D0)", type = str)
    parser.add_argument("romfile", help = "the assembled rom file to be loaded", type = str) 
    parser.add_argument("-r", action = "store_true", help = "run program after upload.")
    args = parser.parse_args()

    # decode args
    rom    = args.romfile
    offset = int(args.offset, 16)

    # open file
    try:
        f = open(rom, 'rb')
    except FileNotFoundError as e:
        print("File \'" + rom + "\' not found!")
        exit()

    # check if offset is within range
    if offset > 0xFFFF:
        print("Offset \'" + str(hex(offset)) + "\' out of range!")
        exit()

    # init serial 
    print("Connecting to serial device...")
    try:
        device = serial.tools.list_ports.comports()[0].device
        global g_ser
        g_ser = serial.Serial(device, g_rate)
    except IndexError:
        print("No available serial device detected!")
        exit()

    time.sleep(3)

    # set address
    print("Setting TPC program counter...")
    cmd = 'X ' + format(offset, 'x').upper()
    write_line(cmd)
    time.sleep(1)

    print("\nCopying rom file to TPC...", flush = True)
    while True:
        # read 16 bytes at a time
        buf = f.read(32)
        out = 'W '
        for i, b in enumerate(buf):
            out = out + '{:02X}'.format(buf[i]) + ' '
        write_line(out)
        if len(buf) < 32:
            break
        time.sleep(g_line_delay)

    print("\nDone!")

    if args.r:
        print("\nAutostarting program...")
        time.sleep(g_line_delay)
        cmd = 'X ' + format(offset, 'x').upper()
        write_line(cmd)
        time.sleep(g_line_delay * 2)
        cmd = 'R'
        write_line(cmd)
        time.sleep(g_line_delay)
        print("\nDone!")

    g_ser.close()

    

def write_line(string):
    s = string + '\r'
    for c in s:
        g_ser.write(str.encode(c))
        print('.', end = '', flush = True)
        time.sleep(g_char_delay)
    g_ser.flush()
    g_ser.reset_input_buffer()



if __name__ == '__main__':
    main()

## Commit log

2025-02-01 TCPU816 - Version 1.1
    [8_16_computer_2-B_Mask.gbs, 8_16_computer_2-B_Paste.gbp, 8_16_computer_2-B_Silkscreen.gbo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]
2025-02-01 Expansion cards uploaded
    [8_16_computer_2_exbus.kicad_pcb, 8_16_computer_2_exbus.kicad_sch, 8_16_computer_2_interface_card.kicad_pcb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]
2026-04-22 New microcode assembler program added.

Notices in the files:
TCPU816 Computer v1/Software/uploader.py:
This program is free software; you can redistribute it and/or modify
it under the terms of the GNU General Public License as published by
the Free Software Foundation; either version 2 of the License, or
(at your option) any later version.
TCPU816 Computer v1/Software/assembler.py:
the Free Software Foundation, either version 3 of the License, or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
